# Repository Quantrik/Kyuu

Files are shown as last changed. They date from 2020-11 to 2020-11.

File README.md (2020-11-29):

# Kyuu
This repository contains the design for the Kyuu Keyboard. While there will be sales of the keyboard
in the future, this repository provides the files necessary for anyone to create a copy of the board for
personal use.

## Terms of Use
Please refer to the LICENSE.md file in this repository for the terms of use. The purpose of sharing
the design is so others may create their own copy of the keyboard if they wish while also preventing
the commercial re-use of the design.

## Working with the Files
The following software is recommend to work with the Case/PCB design files.

* [Fusion 360](https://www.autodesk.com/products/fusion-360/overview)
* [KiCAD](https://kicad.org/)

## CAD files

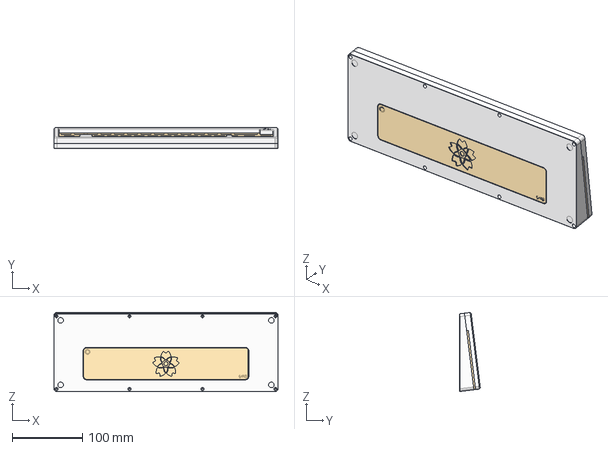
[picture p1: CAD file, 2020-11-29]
Kyuu.step
319.8 x 29.6 x 112.8 mm

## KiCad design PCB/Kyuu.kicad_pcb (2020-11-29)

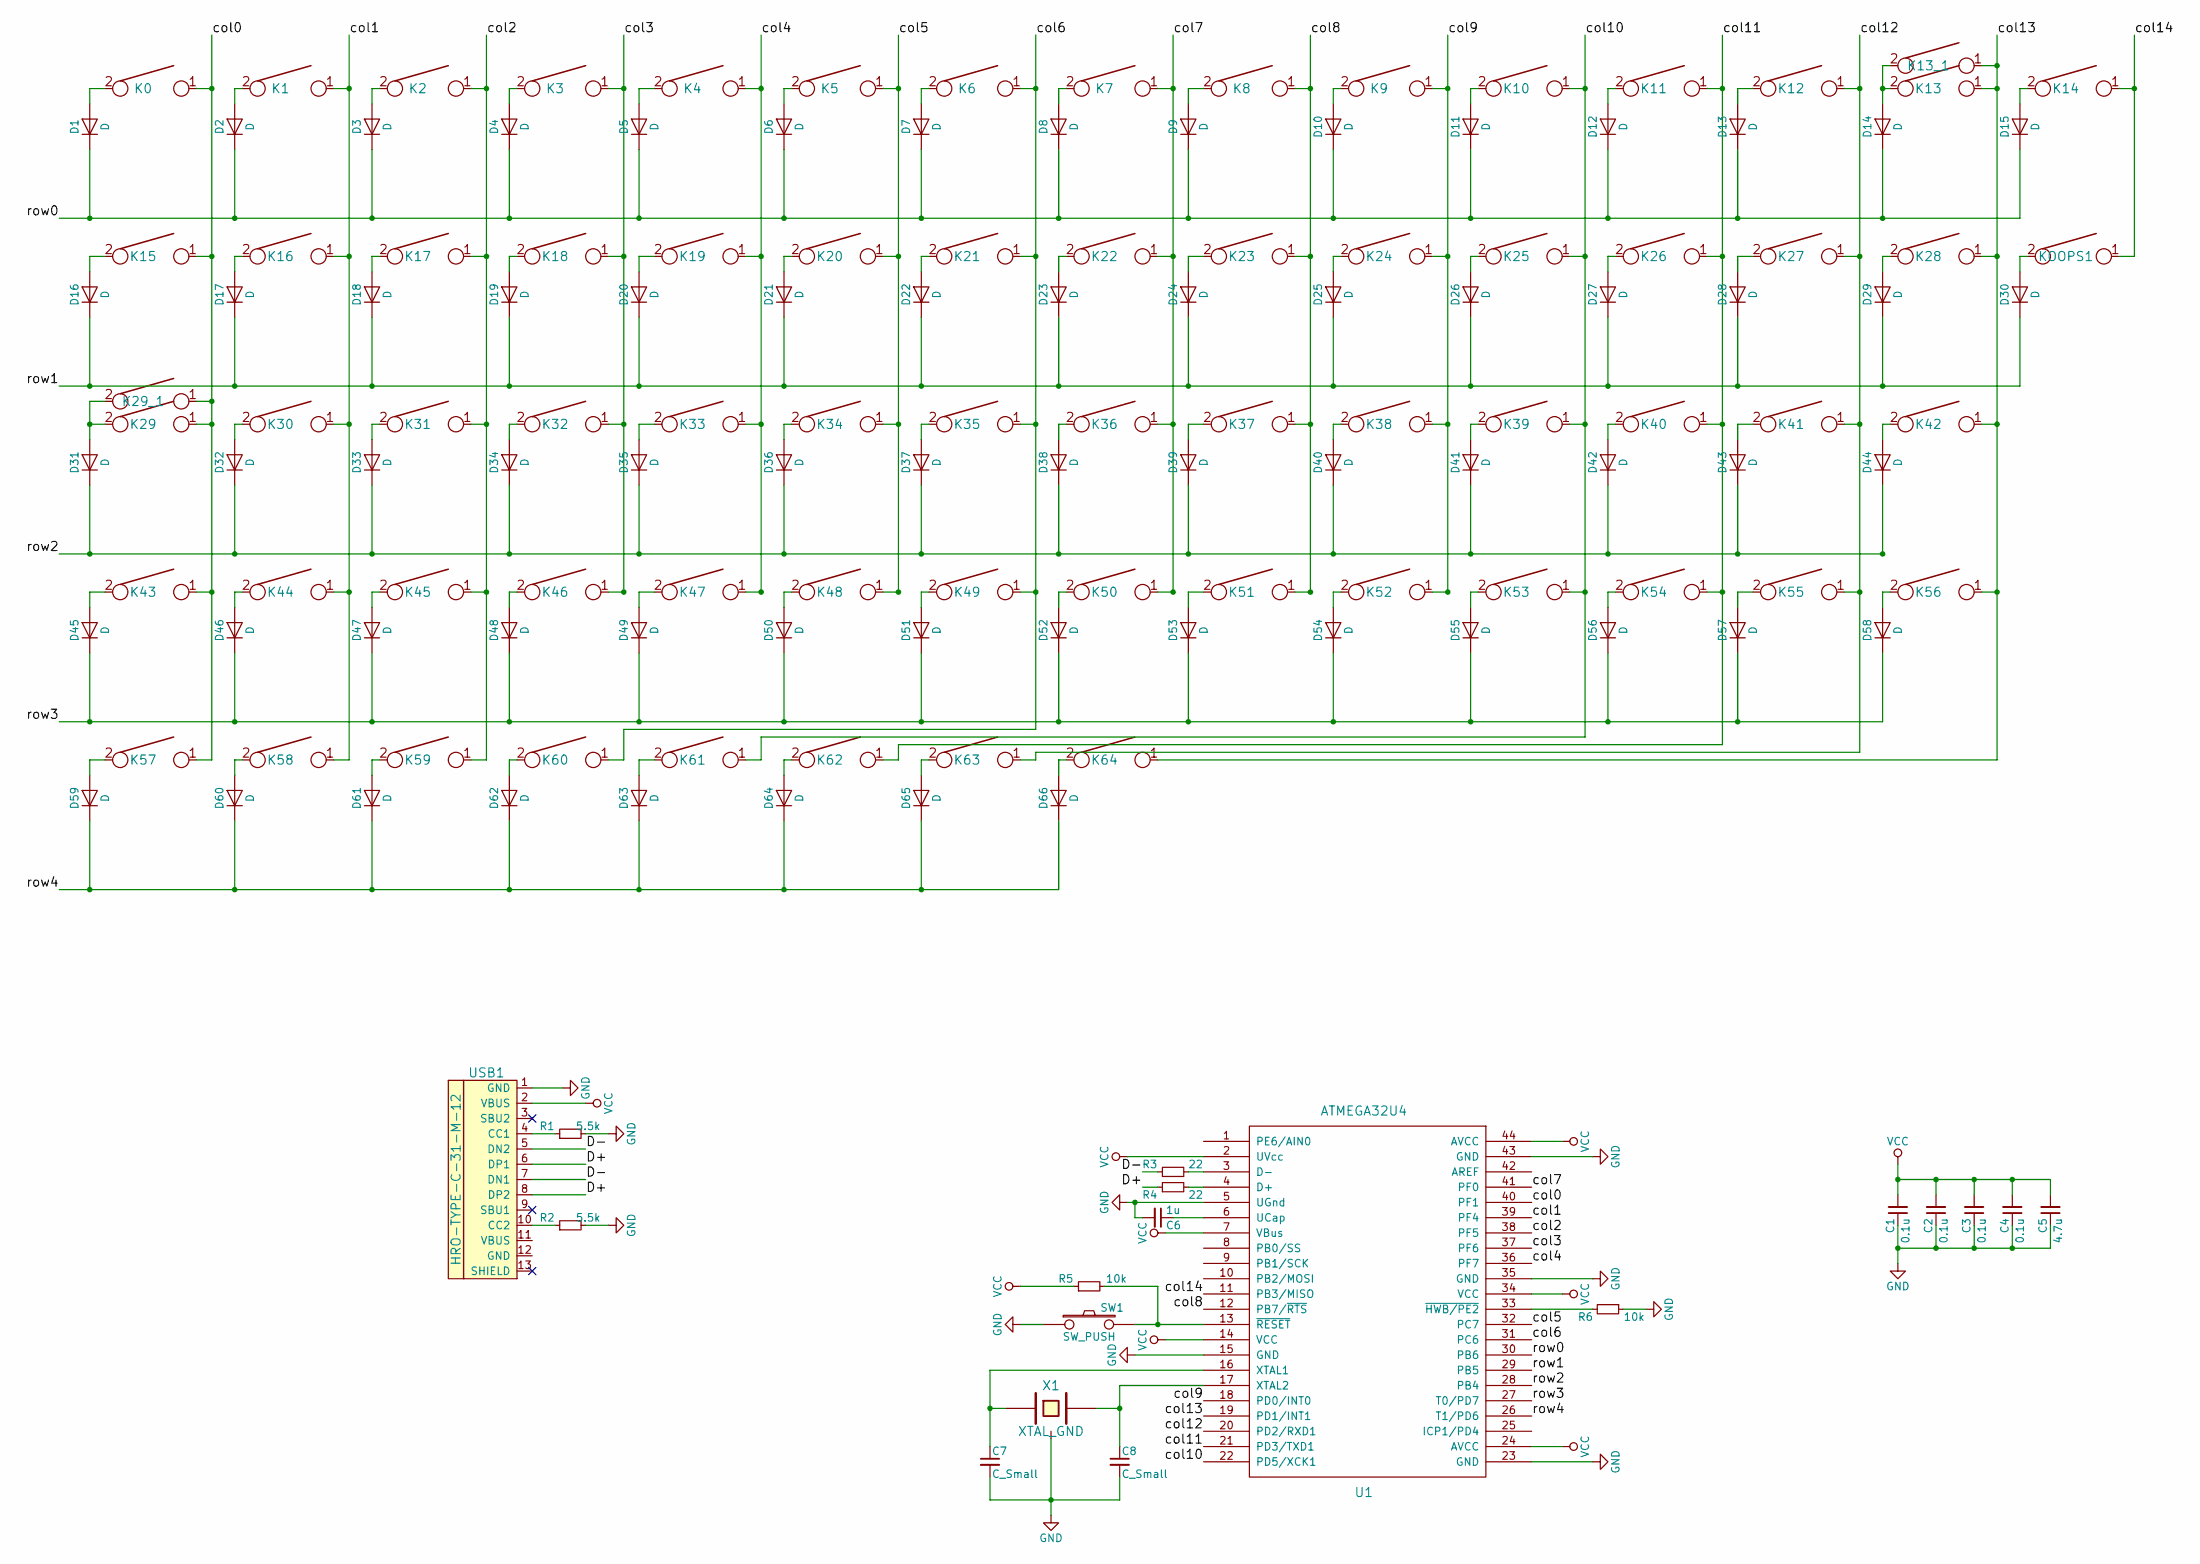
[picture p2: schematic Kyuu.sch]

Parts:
C1, C2, C3, C4: 0.1u; C_0603_HandSoldering
C5: 4.7u; C_0603_HandSoldering
C6: 1u; C_0603_HandSoldering
C7, C8: C_Small; C_0603_HandSoldering
D1, D2, D3, D4, D5, D6, D7, D8, D9, D10, D11, D12, D13, D14, D15, D16, D17, D18, D19, D20, D21, D22, D23, D24, D25, D26, D27, D28, D29, D30, D31, D32, D33, D34, D35, D36, D37, D38, D39, D40, D41, D42, D43, D44, D45, D46, D47, D48, D49, D50, D51, D52, D53, D54, D55, D56, D57, D58, D59, D60, D61, D62, D63, D64, D65, D66: D; D_SOD-123
K0, K1, K2, K3, K4, K5, K6, K7, K8, K9, K10, K11, K12, K13_1, K14, K16, K17, K18, K19, K20, K21, K22, K23, K24, K25, K26, K27, K30, K31, K32, K33, K34, K35, K36, K37, K38, K39, K40, K42, K44, K45, K46, K47, K48, K49, K50, K51, K52, K53, K55, K56, K58, K62, K63, K64: KEYSW; CHERRY_PCB_100H
K13: KEYSW; CHERRY_PCB_200H
K15, K28, K57, K59, K61: KEYSW; CHERRY_PCB_150H
K29, K54: KEYSW; CHERRY_PCB_175H
K29_1: KEYSW; CHERRY_PCB_125H
K41, K43: KEYSW; CHERRY_PCB_225H
K60: KEYSW; CHERRY_PCB_7H
KOOPS1: KEYSW; CHERRY_PCB_100H
R1, R2: 5.5k; R_0603_HandSoldering
R3, R4: 22; R_0603_HandSoldering
R5, R6: 10k; R_0603_HandSoldering
SW1: SW_PUSH; SW_SPST_TL3342
U1: ATMEGA32U4; TQFP-44_10x10mm_Pitch0.8mm
USB1: HRO-TYPE-C-31-M-12
X1: XTAL_GND; FA-238

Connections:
/D+: R4.1, USB1.6 (DP1), USB1.8 (DP2)
/D-: R3.1, USB1.5 (DN2), USB1.7 (DN1)
/col0: K0.1, K15.1, K29.1, K29_1.1, K43.1, K57.1, U1.40 (PF1)
/col1: K1.1, K16.1, K30.1, K44.1, K58.1, U1.39 (PF4)
/col2: K2.1, K17.1, K31.1, K45.1, K59.1, U1.38 (PF5)
/col3: K3.1, K18.1, K32.1, K46.1, U1.37 (PF6)
/col4: K4.1, K19.1, K33.1, K47.1, U1.36 (PF7)
/col5: K5.1, K20.1, K34.1, K48.1, U1.32 (PC7)
/col6: K6.1, K21.1, K35.1, K49.1, K60.1, U1.31 (PC6)
/col7: K7.1, K22.1, K36.1, K50.1, U1.41 (PF0)
/col8: K8.1, K23.1, K37.1, K51.1, U1.12 (PB7/~RTS)
/col9: K9.1, K24.1, K38.1, K52.1, U1.18 (PD0/INT0)
/col10: K10.1, K25.1, K39.1, K53.1, K61.1, U1.22 (PD5/XCK1)
/col11: K11.1, K26.1, K40.1, K54.1, K62.1, U1.21 (PD3/TXD1)
/col12: K12.1, K27.1, K41.1, K55.1, K63.1, U1.20 (PD2/RXD1)
/col13: K13.1, K13_1.1, K28.1, K42.1, K56.1, K64.1, U1.19 (PD1/INT1)
/col14: K14.1, KOOPS1.1, U1.11 (PB3/MISO); also elsewhere on the board
/row0: D1.1 (K), D2.1 (K), D3.1 (K), D4.1 (K), D5.1 (K), D6.1 (K), D7.1 (K), D8.1 (K), D9.1 (K), D10.1 (K), D11.1 (K), D12.1 (K), D13.1 (K), D14.1 (K), D15.1 (K), U1.30 (PB6)
/row1: D16.1 (K), D17.1 (K), D18.1 (K), D19.1 (K), D20.1 (K), D21.1 (K), D22.1 (K), D23.1 (K), D24.1 (K), D25.1 (K), D26.1 (K), D27.1 (K), D28.1 (K), D29.1 (K), D30.1 (K), U1.29 (PB5)
/row2: D31.1 (K), D32.1 (K), D33.1 (K), D34.1 (K), D35.1 (K), D36.1 (K), D37.1 (K), D38.1 (K), D39.1 (K), D40.1 (K), D41.1 (K), D42.1 (K), D43.1 (K), D44.1 (K), U1.28 (PB4); also elsewhere on the board
/row3: D45.1 (K), D46.1 (K), D47.1 (K), D48.1 (K), D49.1 (K), D50.1 (K), D51.1 (K), D52.1 (K), D53.1 (K), D54.1 (K), D55.1 (K), D56.1 (K), D57.1 (K), D58.1 (K), U1.27 (T0/PD7)
/row4: D59.1 (K), D60.1 (K), D61.1 (K), D62.1 (K), D63.1 (K), D64.1 (K), D65.1 (K), D66.1 (K), U1.26 (T1/PD6)
GND: C1.1, C2.1, C3.1, C4.1, C5.1, C6.2, C7.2, C8.2, R1.2, R2.2, R6.1, SW1.1, U1.5 (UGnd), U1.15 (GND), U1.23 (GND), U1.35 (GND), U1.43 (GND), USB1.1 (GND), X1.3
unnamed: C6.1, U1.6 (UCap)
unnamed: C7.1, U1.16 (XTAL1), X1.1
unnamed: C8.1, U1.17 (XTAL2), X1.2
unnamed: D1.2 (A), K0.2
unnamed: D2.2 (A), K1.2
unnamed: D3.2 (A), K2.2
unnamed: D4.2 (A), K3.2
unnamed: D5.2 (A), K4.2
unnamed: D6.2 (A), K5.2
unnamed: D7.2 (A), K6.2
unnamed: D8.2 (A), K7.2
unnamed: D9.2 (A), K8.2
unnamed: D10.2 (A), K9.2
unnamed: D11.2 (A), K10.2
unnamed: D12.2 (A), K11.2
unnamed: D13.2 (A), K12.2
unnamed: D14.2 (A), K13.2, K13_1.2
unnamed: D15.2 (A), K14.2
unnamed: D16.2 (A), K15.2
unnamed: D17.2 (A), K16.2
unnamed: D18.2 (A), K17.2
unnamed: D19.2 (A), K18.2
unnamed: D20.2 (A), K19.2
unnamed: D21.2 (A), K20.2
unnamed: D22.2 (A), K21.2
unnamed: D23.2 (A), K22.2
unnamed: D24.2 (A), K23.2
unnamed: D25.2 (A), K24.2
unnamed: D26.2 (A), K25.2
unnamed: D27.2 (A), K26.2
unnamed: D28.2 (A), K27.2
unnamed: D29.2 (A), K28.2
unnamed: D30.2 (A), KOOPS1.2
unnamed: D31.2 (A), K29.2, K29_1.2
unnamed: D32.2 (A), K30.2
unnamed: D33.2 (A), K31.2
unnamed: D34.2 (A), K32.2
unnamed: D35.2 (A), K33.2
unnamed: D36.2 (A), K34.2
unnamed: D37.2 (A), K35.2
unnamed: D38.2 (A), K36.2
unnamed: D39.2 (A), K37.2
unnamed: D40.2 (A), K38.2
unnamed: D41.2 (A), K39.2
unnamed: D42.2 (A), K40.2
unnamed: D43.2 (A), K41.2
unnamed 69: D44.2 (A), K42.2; also elsewhere on the board
unnamed: D45.2 (A), K43.2
unnamed: D46.2 (A), K44.2
unnamed: D47.2 (A), K45.2
unnamed: D48.2 (A), K46.2
unnamed: D49.2 (A), K47.2
unnamed: D50.2 (A), K48.2
unnamed: D51.2 (A), K49.2
unnamed: D52.2 (A), K50.2
unnamed: D53.2 (A), K51.2
unnamed: D54.2 (A), K52.2
unnamed: D55.2 (A), K53.2
unnamed: D56.2 (A), K54.2
unnamed: D57.2 (A), K55.2
unnamed: D58.2 (A), K56.2
unnamed: D59.2 (A), K57.2
unnamed: D60.2 (A), K58.2
unnamed: D61.2 (A), K59.2
unnamed: D62.2 (A), K60.2
unnamed: D63.2 (A), K61.2
unnamed: D64.2 (A), K62.2
unnamed: D65.2 (A), K63.2
unnamed: D66.2 (A), K64.2
unnamed: R1.1, USB1.4 (CC1)
unnamed: R2.1, USB1.10 (CC2)
unnamed: R3.2, U1.3 (D-)
unnamed: R4.2, U1.4 (D+)
unnamed: R5.2, SW1.2, U1.13 (~RESET)
unnamed: R6.2, U1.33 (~HWB/PE2)
VCC: C1.2, C2.2, C3.2, C4.2, C5.2, R5.1, U1.2 (UVcc), U1.7 (VBus), U1.14 (VCC), U1.24 (AVCC), U1.34 (VCC), U1.44 (AVCC), USB1.2 (VBUS)

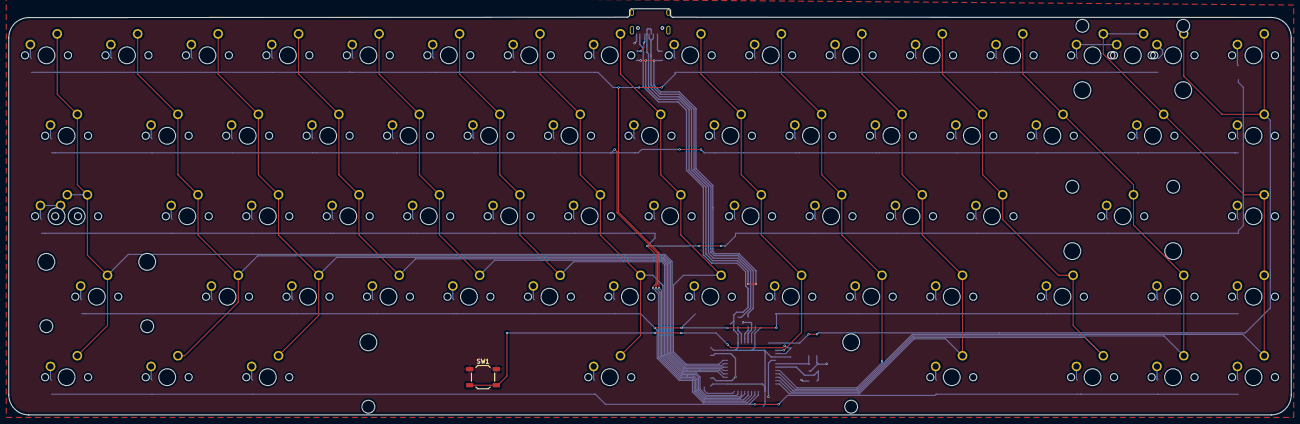
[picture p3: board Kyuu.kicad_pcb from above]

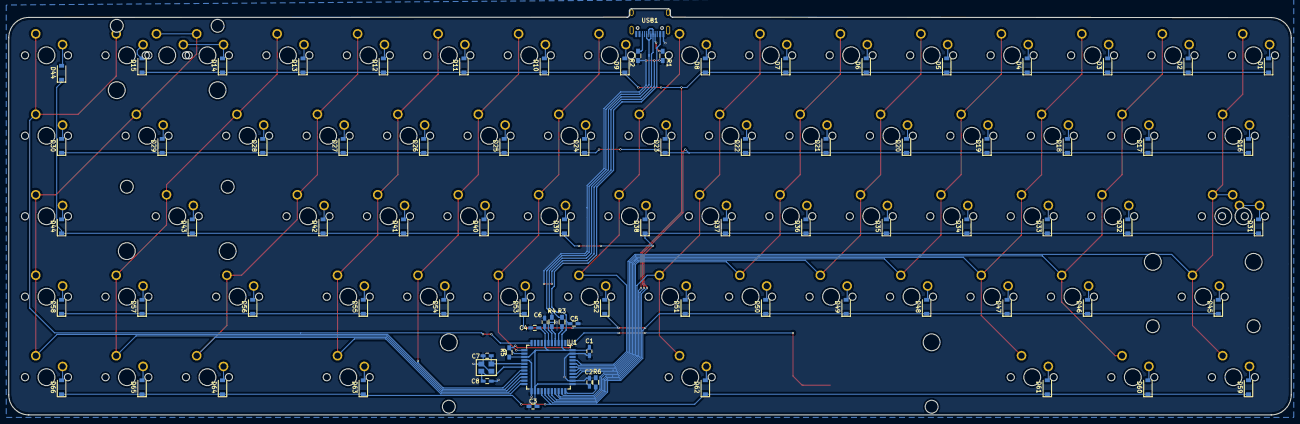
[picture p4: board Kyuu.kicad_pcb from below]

Board: 2 copper layers, 303.6 x 96.1 mm, 154 parts (84 on the bottom side), 99 nets.

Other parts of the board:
D44#2: D; D_SOD-123
K14_1: KEYSW; CHERRY_PCB_100H

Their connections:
/col14: K14_1.1; also elsewhere on the board
/row2: D44#2.1; also elsewhere on the board
unnamed 69: D44#2.2, K14_1.2; also elsewhere on the board

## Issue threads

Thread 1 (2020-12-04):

rar and or zip files unavailable

IOPNR, 2020-12-04:
Hello, first and foremost - Thank you for releasing your designs to the community for personal use. Your design is iconic and I'm pretty stoked to be able to build my very own and I'm sure many others in the community are as well.

I'm writing with regard to uploading the pcb files for printing - I am unable to find a rar and or zip file within the pcb branch of your repository. Am I missing something? I had to do a workaround for the case files as well but managed to figure it out. Any help would be greatly appreciated.

All best to you and yours!

ctrltri, 2020-12-04:
You need to clone the repository and all the files will be there.

Quantrik, 2020-12-14:
You can look at the `gerbers` directory. They contain the output files that should be added to a `zip` or `tar` package.

Closed 2020-12-14.

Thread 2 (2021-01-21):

PCB Parts

YodaImperium, 2021-01-21:
For my personal Kyuu build I just ordered a PCB based on the gerber files and now I want to order all the parts that I have to solder onto it. For some parts there are some specifications (i.e.: 2x 5.5k Resistors) but I'm confused about the diodes (D) and the capacitors (C7,C8). So here are my questions:
- What diodes do I need or are all SOD-123 diodes viable?
- What capacitors do I need for C7 and C8? All other capacitors say something like 0.1u but for C7 and C8 there is just C_Small.

I hope my questions aren't stupid because I never did anything like this before and btw I love your keyboard^^

athammana, 2021-03-01:
@YodaImperium Did you ever figure out what parts need to be ordered? I'm in the process of getting one myself.

athammana, 2021-03-08:
Hey if someone is still looking for these values, look at this guide: [guide](https://github.com/ruiqimao/keyboard-pcb-guide). I'm pretty sure the kyuu was built based off of that. I haven't tested it myself, but I think everything it almost identical between them.

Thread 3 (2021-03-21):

WK Version

ChuckD3ath, 2021-03-21:
Hello! Is it possible to have file for the WK version as well instead of only WKL?

I'm not really a fan of WKL layout but would like to try and get Kyuu made for myself. Thank you.

ratchet303, 2021-10-17:
A little late, but I was looking into building a WK Kyuu. Here is a .step file I made for a WK Kyuu, and it seems the plate and PCB designs already have the windows key, there was just a blocker for the WKL version (someone correct me if I'm wrong).
[https://drive.google.com/file/d/1QS4Nr9sc4B6cRykTrNMsWIS5eKDg6lz1/view?usp=sharing](url)

Closed 2021-10-17.

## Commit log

2020-11-29 Add CAD design
    [Kyuu.step]
2020-11-29 Create PCB README.md
2020-11-29 Add PCB files
    [Kyuu-B.Cu.gbl, Kyuu-B.Mask.gbs, Kyuu-B.Paste.gbp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]
2020-11-29 Create gerber
2020-11-29 Add KiCAD PCB project
    [Kyuu-B.Cu.gbl, Kyuu-B.Mask.gbs, Kyuu-B.Paste.gbp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]
